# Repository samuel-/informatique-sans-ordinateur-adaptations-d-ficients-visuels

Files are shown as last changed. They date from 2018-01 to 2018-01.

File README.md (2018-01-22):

# Informatique sans ordinateur — adaptations pour déficients visuels

L’informatique débranchée ?

Il s’agit de parler d’informatique, de programmation, d’appréhender les concepts qu’il y a derrière, mais sans utiliser d’ordinateur, qui peut faire peur ou détourner l’attention.
Entre autres, jeu du robot idiot, binaire, coder des images, crêpier psychorigide, etc.

L’idée était de réfléchir à comment adapter ces jeux pour les déficients visuels (malvoyant·e·s et non-voyant·e·s). Nous nous sommes intéressés à deux outils en particulier :

* Le jeu du code correcteur d’erreur: un tour de magie qui utilise la parité comme clé de contrôle, ça a l’air barbare mais venez voir, on est de mauvais magiciens on donne notre secret. Cette activité est adaptée depuis l'activité *tour de cartes* proposée par [le groupe de recherche Informatique sans Ordinateur de l'IREM de Clermont-Ferrand](http://www.irem.univ-bpclermont.fr/Informatique-sans-Ordinateur). Vous trouverez sur leur page de la documentation à destination des enseignant·e·s.
* Le jeu des images à relier à un petit code qui sert à « fabriquer l’image ».

Ces deux outils ont certaines cartes en commun (chaque carte a deux faces, ce qui correspond à deux états).

Après différents essais, hop !

## Réflexions et choix

Nous avons travaillé pendant plusieurs séances avec quelques membres des [petits débrouillards](http://lespetitsdebrouillards-aura.org/) de Clermont-Ferrand, et avec des membres du [groupe de recherche Informatique sans Ordinateur de l'IREM de Clermont-Ferrand](http://www.irem.univ-bpclermont.fr/Informatique-sans-Ordinateur), avec quelques personnes en situation de déficience visuelle, afin de prendre en compte à la fois les aspects pédagogiques et d'accessibilité du matériel proposé.

Nous avons ainsi convenu qu'il fallait fabriquer:

* un jeu où les pièces ne pourraient pas bouger par mauvaise manipulation.
* des pièces réversibles, distinguables rapidement au toucher par un matériau différent, afin d'en faciliter la lecture instantanée.
* un plateau d'une taille peu excessive, afin qu'il tienne facilement sous la main.
* un plateau sans distinction des pixels de l'image et des codes correcteurs d'erreur.
* que les symboles en négatif pour les instructions étaient suffisamment lisibles s'ils étaient bien positionnés, et d'une forme lisible. Ainsi, les flèches sont composées de triangles, où la pulpe du doigt peut facilement descendre, les coins sont symbolisés par des équerres proches du bord, mais suffisamment écartées pour que l'on puisse les localiser facilement.

## Fabrication 

Nous avons opté pour une fabrication par découpe laser de planches de bois et de medium, couplés à un matériau en plastique souple (un tapis de sport). Dans notre cas, nous avons utilisé une ARKETYPE Laser Métal 1325 disponible à [SIGMake](https://sigmake.jimdo.com/), et dont le [manuel d'utilisation](https://sigmake.jimdo.com/app/download/12741731136/D%C3%A9coupe+et+Gravure+laser.pdf?t=1512554719) est proposée par l'équipe sur place.

Les fichiers dxf présents sur ce dépôt permettent de piloter une découpeuse laser. Ils ont été conçus à l'aide d'[OpenSCAD](http://www.openscad.org/) et d'[inkscape](http://inkscape.fr/).

## Illustration

### Code correcteur d'erreur 

Le plateau de jeu utilisé pour l'activité tour de cartes :

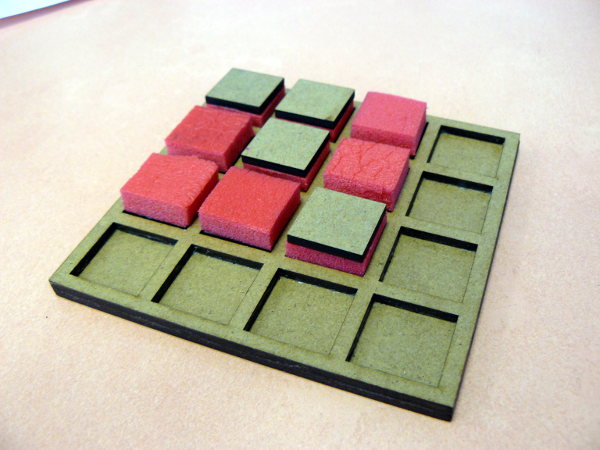
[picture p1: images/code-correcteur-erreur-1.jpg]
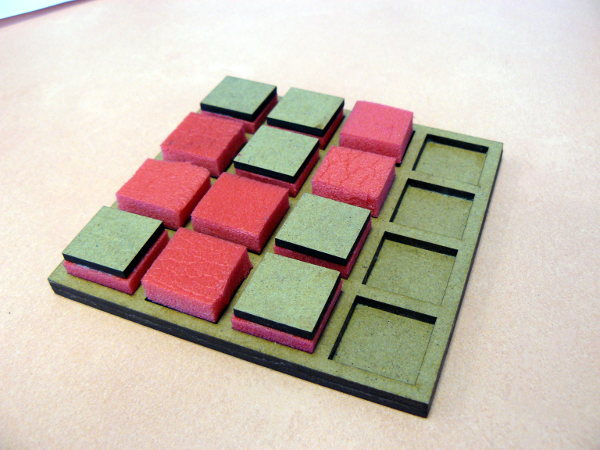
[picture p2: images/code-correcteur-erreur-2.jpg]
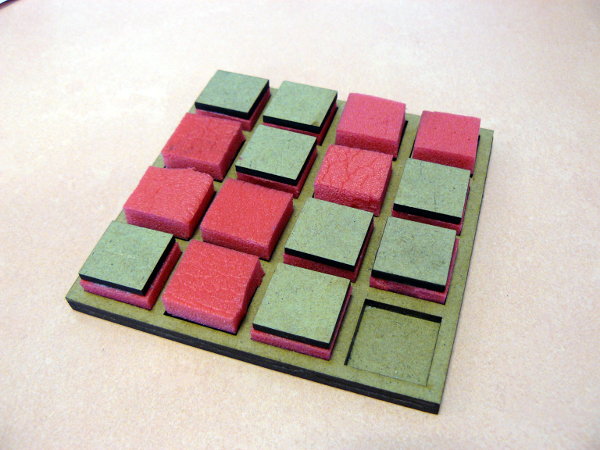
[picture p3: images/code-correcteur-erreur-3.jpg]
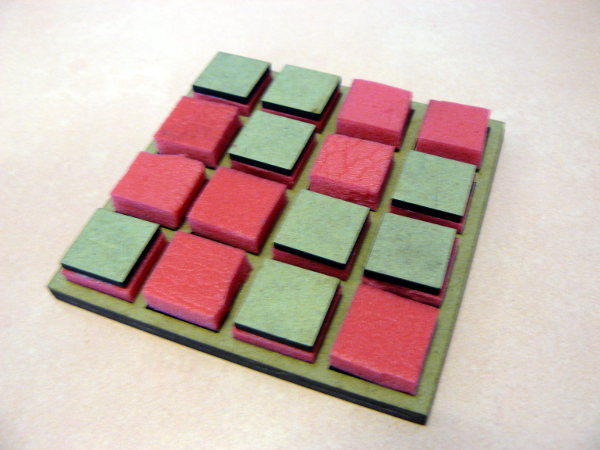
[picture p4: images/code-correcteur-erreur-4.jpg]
   

Le plateau de jeu utilisé pour l'activité codage d'images :

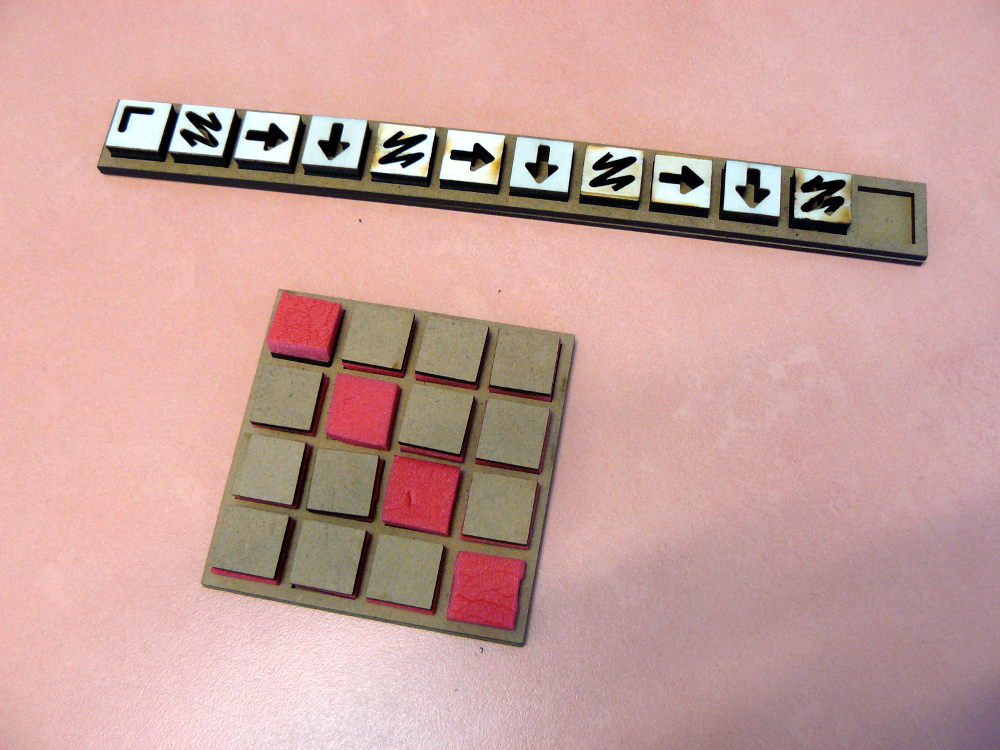
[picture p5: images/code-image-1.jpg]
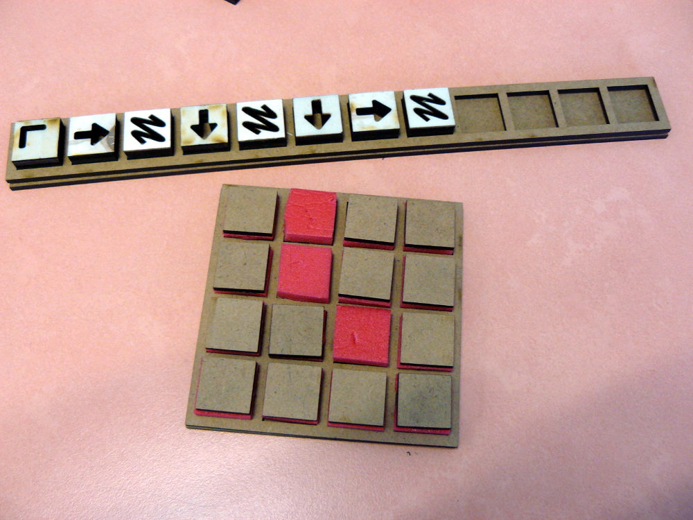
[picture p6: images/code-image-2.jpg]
 

## Historique des réunions

En plus des réunions régulières de fabrication à SIGMake, le groupe de travail informel autour de ce projet s'est réuni dans les locaux de l'association les petits débrouillards:

* [Annonce de la première réunion](http://lespetitsdebrouillards-aura.org/event/soiree-3n-informatique-debranchee-et-deficience-visuelle-1/)
* [Annonce de la seconde réunion](http://lespetitsdebrouillards-aura.org/event/soiree-3n-informatique-debranchee-et-deficience-visuelle-2/)

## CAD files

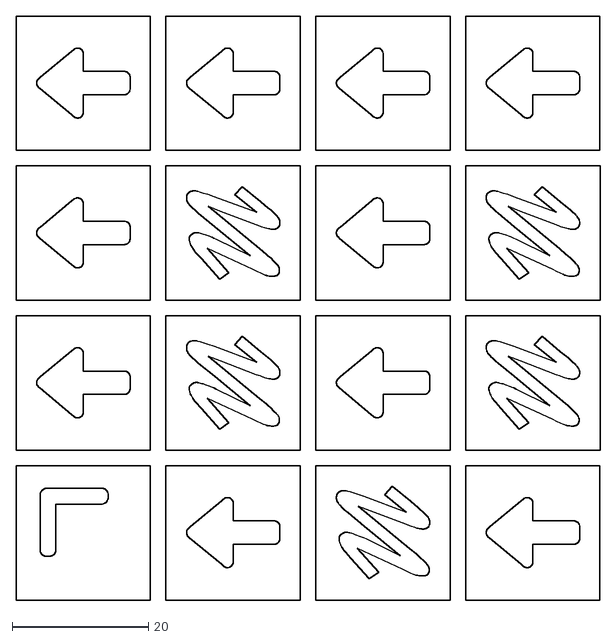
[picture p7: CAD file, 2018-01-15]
cartes-set.dxf
85.7 x 85.7

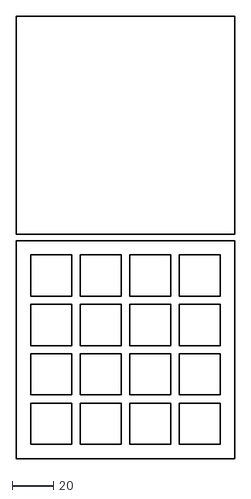
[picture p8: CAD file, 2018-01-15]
reglette.dxf
106.0 x 215.0

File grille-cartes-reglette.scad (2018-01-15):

c=20;   //côté carré
m=4;    //marge inter-carré
mp=7;  //marge plateau

module quadrillage(imax,jmax){
for(i = [1 : imax],j = [1 : jmax])
    translate([(i-1)*(c+m),(j-1)*(c+m)])
    cube(c);
    }

module plateau(imax=4,jmax=4){
    px=imax*(c+m)-m+2*mp;
    py=jmax*(c+m)-m+2*mp;
    echo("dimensions plateau :",px,py); 
    projection()
    difference(){
        cube([px,py,3]);
        translate([mp,mp,-1])
        quadrillage(imax=imax,jmax=jmax);
    }
    projection()
        translate([0,py+3,0])
        cube([px,py,3]);
}

plateau(imax=4,jmax=4);
translate([111+3,0,0])
plateau(imax=12,jmax=1);

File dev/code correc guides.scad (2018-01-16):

c=20;   //côté carré
m=4;    //marge
mm=13;  //marge ac code correcteur
mp=5;  //marge plateau
imax=4; // nb colonnes
jmax=4; // nb lignes
lguide1=3; // largeur du guide impair
lguide2=12; // largeur du guide pair
eguide=3; // épaisseur guide
i=0;
j=0;
//projection(cut = true) 

module quadrillage(f=0){
for(i = [1 : imax],j = [1 : jmax])
    //echo(c);    
    translate([(i-1)*(c+m),(j-1)*(c+m)])
    if (f==0) cube(c);
        else translate([c/2,c/2,0]) cylinder(c,d=c);
for(i = [1 : imax])
    translate([(i-1)*(c+m),jmax*(c+m)+mm])
    if (f==0) cube(c);
        else translate([c/2,c/2,0]) cylinder(c,d=c);
for(j = [1 : jmax])
    translate([imax*(c+m)+mm,(j-1)*(c+m)])
    if (f==0) cube(c);
        else translate([c/2,c/2,0]) cylinder(c,d=c);
}

module guidev() {
    
}

module guides(){
    for(i = [1 : imax]) {
        if (i % 2 == 0)
            translate([(i-1)*(c+m)+c/2-lguide2/2, -mp,  eguide - 1])
            cube([lguide2, py, e]);
        else
            translate([(i-1)*(c+m)+c/2-lguide1/2, -mp,  eguide - 1])
            cube([lguide1, py, e]);;
    }
    for(j = [1 : jmax]) {
         if (j % 2 == 0)
            translate([-mp,(j-1)*(c+m)+c/2-lguide2/2,  eguide - 1])
           cube([px, lguide2, e]);
         else
            translate([-mp,(j-1)*(c+m)+c/2-lguide1/2,  eguide - 1])
           cube([px, lguide1, e]);
    }
}

//plateau
module plateau(f=0,g=1){
    px=imax*(c+m)+(c+mm)+2*mp;
    py=jmax*(c+m)+(c+mm)+2*mp;
    echo("dimensions plateau :",px,py);
    e = min(c,m,mm,mp)-1.5;
    if(g==0)
    difference(){
        union(){
            cube([px,py,e]);
            translate([mp,mp,-1]) guides(e=e, c=c, px=px, py=py,m=m,mm=mm,mp=mp,imax=imax,jmax=jmax);
        }
        translate([mp,mp,-1]) quadrillage(f=f,c=c,m=m,mm=mm,mp=mp,imax=imax,jmax=jmax);
    }
    else if(g==1)
    projection()
    difference(){
        cube([px,py,e]);
        translate([mp,mp,-1]) quadrillage(f=f,c=c,m=m,mm=mm,mp=mp,imax=imax,jmax=jmax);
    }
    else if(g==2)
    projection()
    difference(){
        translate([mp,mp,-1]) guides(e=e, c=c, px=px, py=py,m=m,mm=mm,mp=mp,imax=imax,jmax=jmax);
        translate([mp,mp,-1]) quadrillage(f=f,c=c,m=m,mm=mm,mp=mp,imax=imax,jmax=jmax);
    }
}

module SeparateChildrenX(space){
    for ( i= [0:1:$children-1])   // step needed in case $children < 2  
        translate([i*space,0,0]) children(i);
}
module SeparateChildrenY(space){
    for ( i= [0:1:$children-1])   // step needed in case $children < 2  
        translate([0,i*space,0]) children(i);
}



SeparateChildrenY(250){
    SeparateChildrenX(250){
        plateau(c=20,f=0);
        plateau(c=30,f=0);
        plateau(c=35,f=0);
    //    plateau(c=40,m=7,mm=12,f=0);
    }
    SeparateChildrenX(250){
    //    plateau(c=35.5,f=1);
    //    plateau(c=35.5,m=5,mm=10,f=1);
    //    plateau(c=35.5,imax=5,jmax=5,f=1);
    }
}

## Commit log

2018-01-16 Reformulation légère de la description du projet
2018-01-16 ajout fichier de travail
    [code correc guides.scad]
2018-01-16 ajout fichiers de travail cartes symboles, cartes gravées
2018-01-16 Enrichissement de la description, avec ajout d'images illustratives
2018-01-18 Mise en forme des événements
